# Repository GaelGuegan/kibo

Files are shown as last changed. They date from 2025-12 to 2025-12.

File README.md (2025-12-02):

# KIBO project

It consists of a panel of 5x5 addressable leds that could be configured through bluetooth.

It is powered by a 3.7V single cell lipo battery, that could be recharged through usb-c.

Leds are controlled by a single GPIO pin with signal passing through a 5V level shifter.

## Software

- Zephyr OS
- Android Studio

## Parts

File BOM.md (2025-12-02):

# BOM

* E73-2G4M08S1C: MCU Module with nRF52840
https://www.fr-ebyte.com/products/E73-2G4M08S1C

* WS2812B-2020: Leds x25
https://docs.nordicsemi.com/bundle/ncs-2.6.1/page/zephyr/samples/drivers/led_ws2812/README.html

* MT3608: Step Up Converter 3.3V -> 5V
https://www.olimex.com/Products/Breadboarding/BB-PWR-3608/resources/MT3608.pdf

* AP2112K-3.3: LDO regulator
https://www.diodes.com/assets/Datasheets/AP2112.pdf

* TP4057: Charger for battery
http://toppwr.com/uploadfile/file/20230304/640302a47b738.pdf

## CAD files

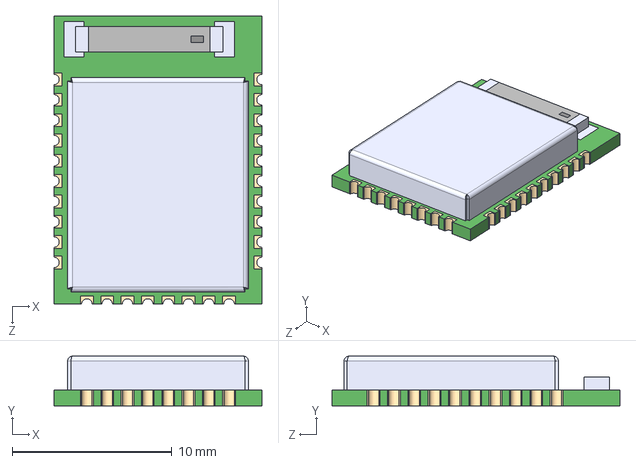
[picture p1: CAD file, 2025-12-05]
E73-2G4M08S1C/E73-2G4M08S1C.step
13.0 x 3.10 x 18.0 mm

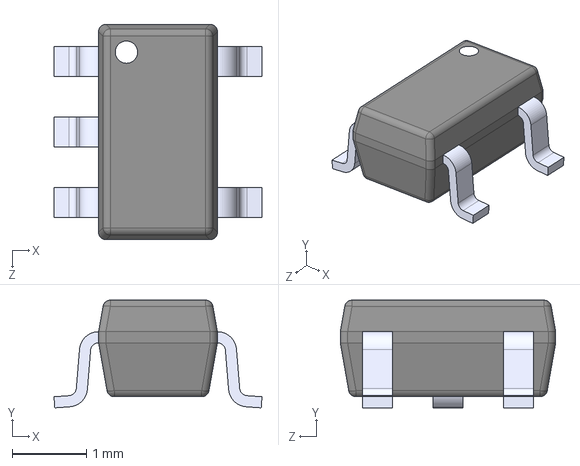
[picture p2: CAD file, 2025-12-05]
SN74AHCT1G125DBVT/SN74AHCT1G125DBVT.step
2.80 x 1.45 x 2.90 mm

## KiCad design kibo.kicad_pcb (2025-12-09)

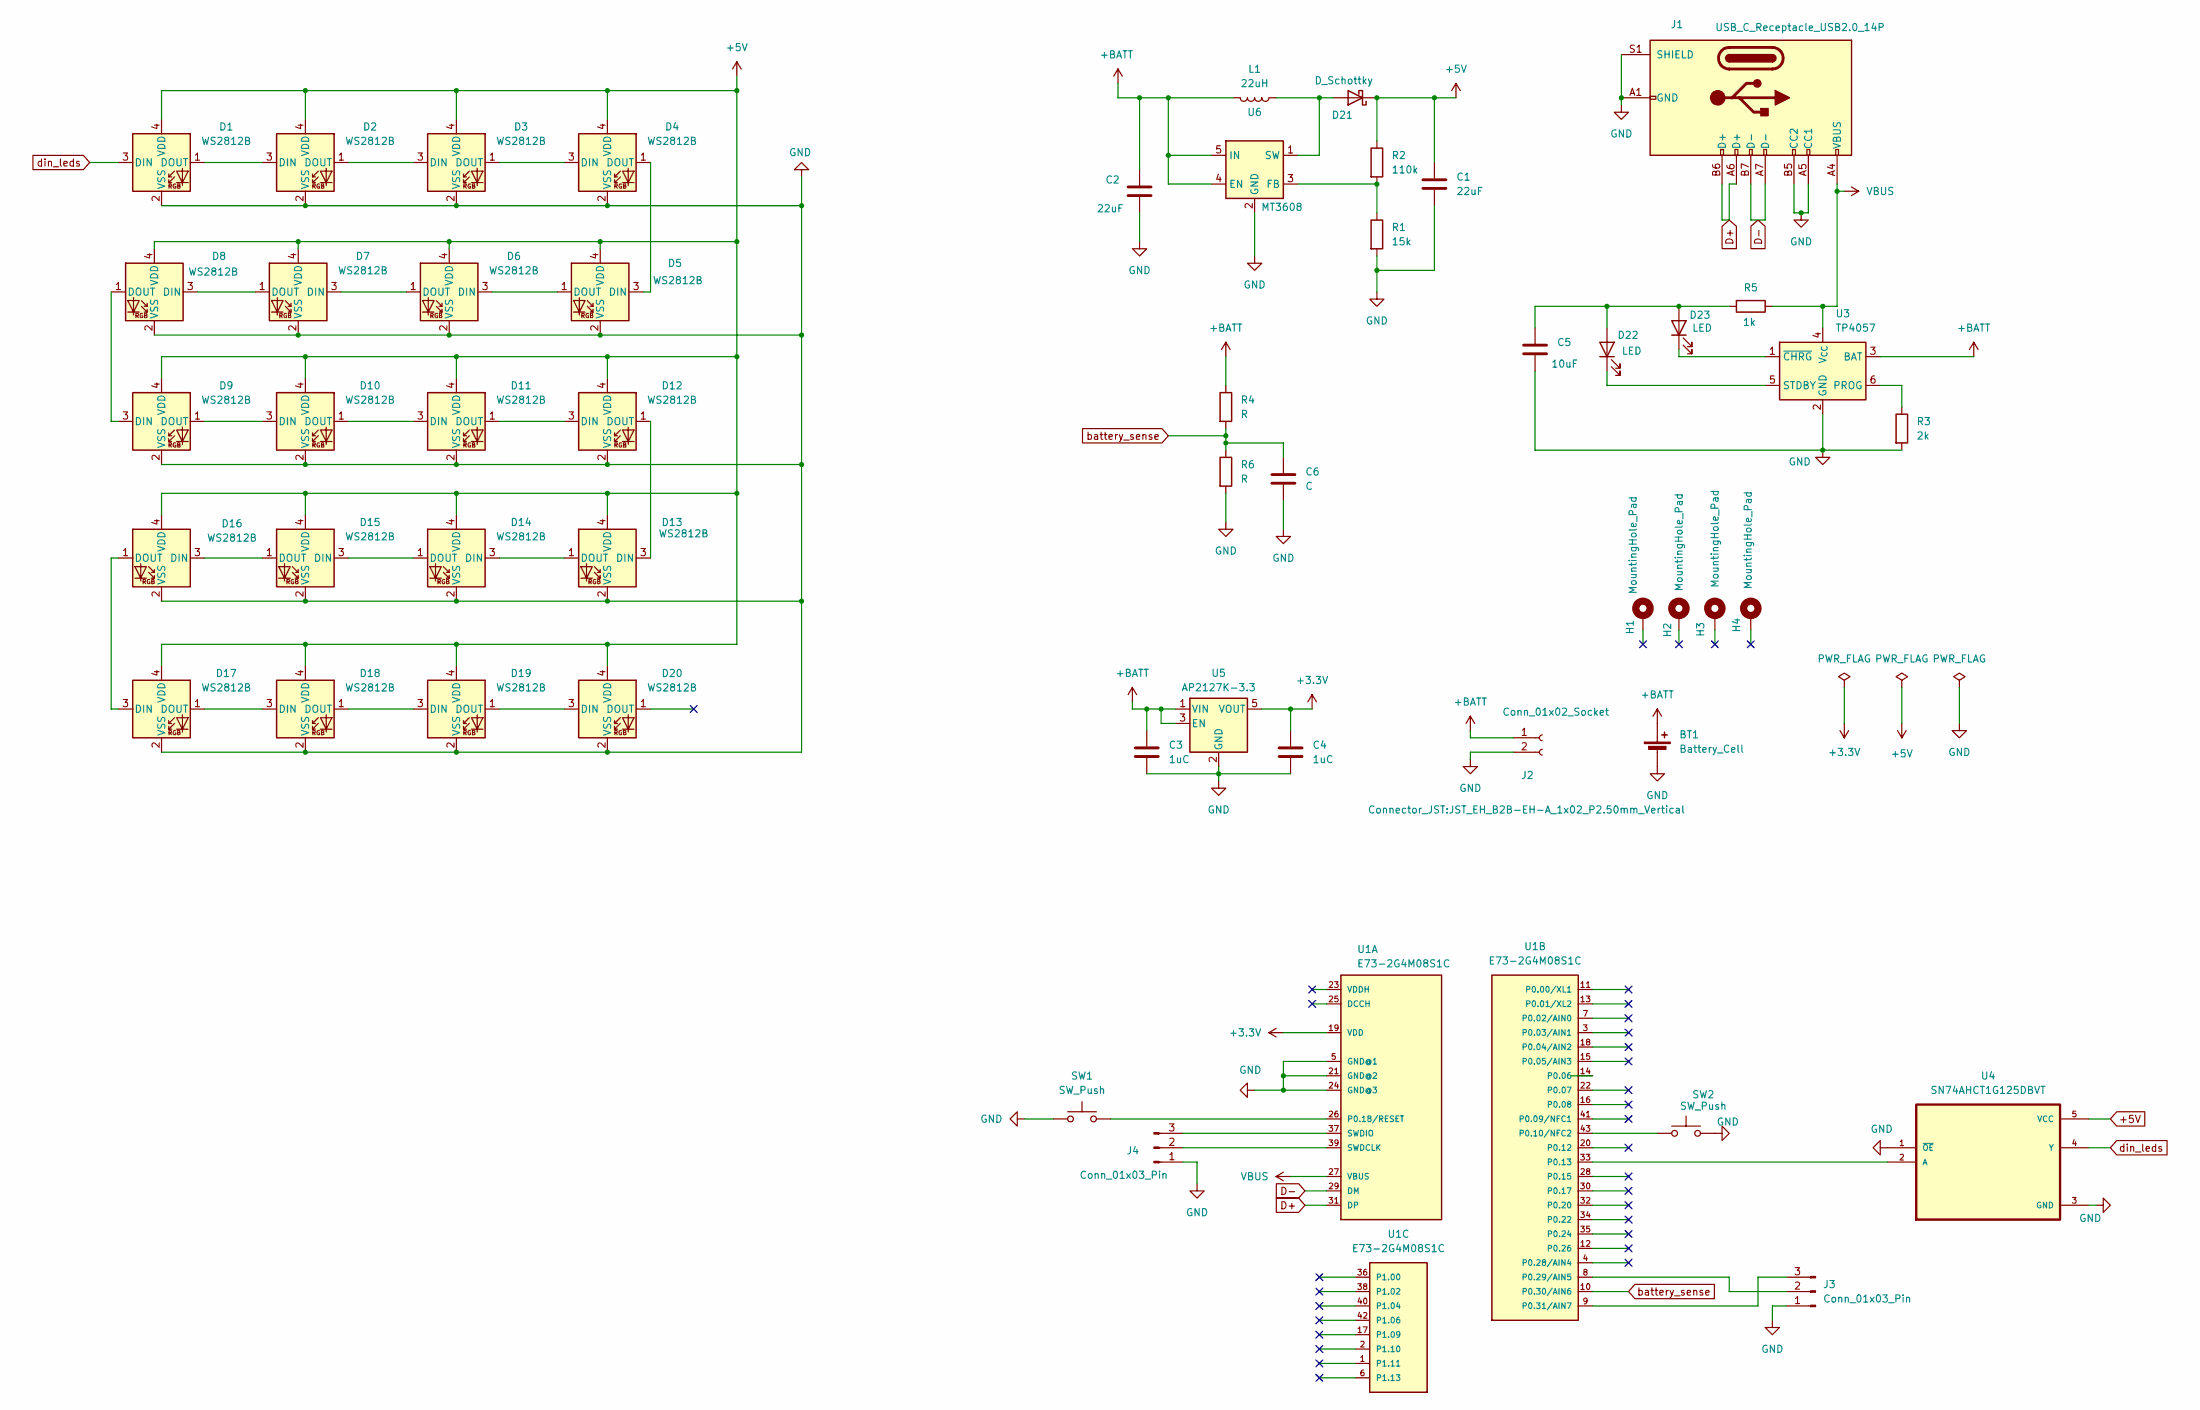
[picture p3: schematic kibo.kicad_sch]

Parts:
BT1: Battery_Cell
C1, C2: 22uF; C_0805_2012Metric
C3, C4: 1uC; C_0805_2012Metric
C5: 10uF; C_0805_2012Metric
C6: C; C_0805_2012Metric
D1, D2, D3, D4, D5, D6, D7, D8, D9, D10, D11, D12, D13, D14, D15, D16, D17, D18, D19, D20: WS2812B; LED_WS2812B-2020_PLCC4_2.0x2.0mm
D21: D_Schottky
D22, D23: LED
H1: MountingHole_Pad; MountingHole_2.5mm_Pad
H2, H3, H4: MountingHole_Pad; MountingHole_2.2mm_M2_Pad
J1: USB_C_Receptacle_USB2.0_14P; USB_C_Receptacle_Palconn_UTC16-G
J2: Conn_01x02_Socket; JST_EH_B2B-EH-A_1x02_P2.50mm_Vertical
J3, J4: Conn_01x03_Pin; PinHeader_1x03_P2.00mm_Vertical
L1: 22uH; L_0805_2012Metric
R1: 15k; R_0805_2012Metric
R2: 110k; R_0805_2012Metric
R3: 2k; R_0805_2012Metric
R4, R6: R; R_0805_2012Metric
R5: 1k; R_0805_2012Metric
SW1, SW2: SW_Push; SW_SPST_EVQP2_ShortPushTravel_H2.5mm
U1: E73-2G4M08S1C
U3: TP4057; TSOT-23-6
U4: SN74AHCT1G125DBVT; SOT95P280X145-5N
U5: AP2127K-3.3; SOT-23-5
U6: MT3608; SOT-23-6

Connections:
+3.3V: C4.1, U1.19 (VDD), U5.5 (VOUT)
+5V: C1.1, D1.4 (VDD), D2.4 (VDD), D3.4 (VDD), D4.4 (VDD), D5.4 (VDD), D6.4 (VDD), D7.4 (VDD), D8.4 (VDD), D9.4 (VDD), D10.4 (VDD), D11.4 (VDD), D12.4 (VDD), D13.4 (VDD), D14.4 (VDD), D15.4 (VDD), D16.4 (VDD), D17.4 (VDD), D18.4 (VDD), D19.4 (VDD), D20.4 (VDD), D21.1 (K), R2.1, U4.5 (VCC)
+BATT: BT1.1 (+), C2.1, C3.1, J2.1, L1.2, R4.1, U3.3 (BAT), U5.1 (VIN), U5.3 (EN), U6.4 (EN), U6.5 (IN)
D+: J1.A6 (D+), J1.B6 (D+), U1.31 (DP)
D-: J1.A7 (D-), J1.B7 (D-), U1.29 (DM)
GND: BT1.2 (-), C1.2, C2.2, C3.2, C4.2, C5.2, C6.2, D1.2 (VSS), D2.2 (VSS), D3.2 (VSS), D4.2 (VSS), D5.2 (VSS), D6.2 (VSS), D7.2 (VSS), D8.2 (VSS), D9.2 (VSS), D10.2 (VSS), D11.2 (VSS), D12.2 (VSS), D13.2 (VSS), D14.2 (VSS), D15.2 (VSS), D16.2 (VSS), D17.2 (VSS), D18.2 (VSS), D19.2 (VSS), D20.2 (VSS), J1.A1 (GND), J1.A5 (CC1), J1.A12 (GND), J1.B1 (GND), J1.B5 (CC2), J1.B12 (GND), J1.S1 (SHIELD), J2.2, J3.1, J4.1, R1.2, R3.2, R6.2, SW1.1, SW2.2, U1.5 (GND@1), U1.21 (GND@2), U1.24 (GND@3), U3.2 (GND), U4.1 (~OE), U4.3 (GND), U5.2 (GND), U6.2 (GND)
unnamed: D1.1 (DOUT), D2.3 (DIN)
unnamed: D2.1 (DOUT), D3.3 (DIN)
unnamed: D3.1 (DOUT), D4.3 (DIN)
unnamed: D4.1 (DOUT), D5.3 (DIN)
unnamed: D5.1 (DOUT), D6.3 (DIN)
unnamed: D6.1 (DOUT), D7.3 (DIN)
unnamed: D7.1 (DOUT), D8.3 (DIN)
unnamed: D8.1 (DOUT), D9.3 (DIN)
unnamed: D9.1 (DOUT), D10.3 (DIN)
unnamed: D10.1 (DOUT), D11.3 (DIN)
unnamed: D11.1 (DOUT), D12.3 (DIN)
unnamed: D12.1 (DOUT), D13.3 (DIN)
unnamed: D13.1 (DOUT), D14.3 (DIN)
unnamed: D14.1 (DOUT), D15.3 (DIN)
unnamed: D15.1 (DOUT), D16.3 (DIN)
unnamed: D16.1 (DOUT), D17.3 (DIN)
unnamed: D17.1 (DOUT), D18.3 (DIN)
unnamed: D18.1 (DOUT), D19.3 (DIN)
unnamed: D19.1 (DOUT), D20.3 (DIN)
unnamed: D21.2 (A), L1.1, U6.1 (SW)
unnamed: C5.1, D22.2 (A), D23.2 (A), R5.2
unnamed: D22.1 (K), U3.5 (STDBY)
unnamed: D23.1 (K), U3.1 (~CHRG)
unnamed: J3.2, U1.8 (P0.29/AIN5)
unnamed: J3.3, U1.9 (P0.31/AIN7)
unnamed: J4.2, U1.39 (SWDCLK)
unnamed: J4.3, U1.37 (SWDIO)
unnamed: SW1.2, U1.26 (P0.18/RESET)
unnamed: SW2.1, U1.43 (P0.10/NFC2)
unnamed: U1.33 (P0.13), U4.2 (A)
unnamed: R3.1, U3.6 (PROG)
unnamed: R1.1, R2.2, U6.3 (FB)
VBUS: J1.A4 (VBUS), J1.A9 (VBUS), J1.B4 (VBUS), J1.B9 (VBUS), R5.1, U1.27 (VBUS), U3.4 (V_{CC})
battery_sense: C6.1, R4.2, R6.1, U1.10 (P0.30/AIN6)
din_leds: D1.3 (DIN), U4.4 (Y)

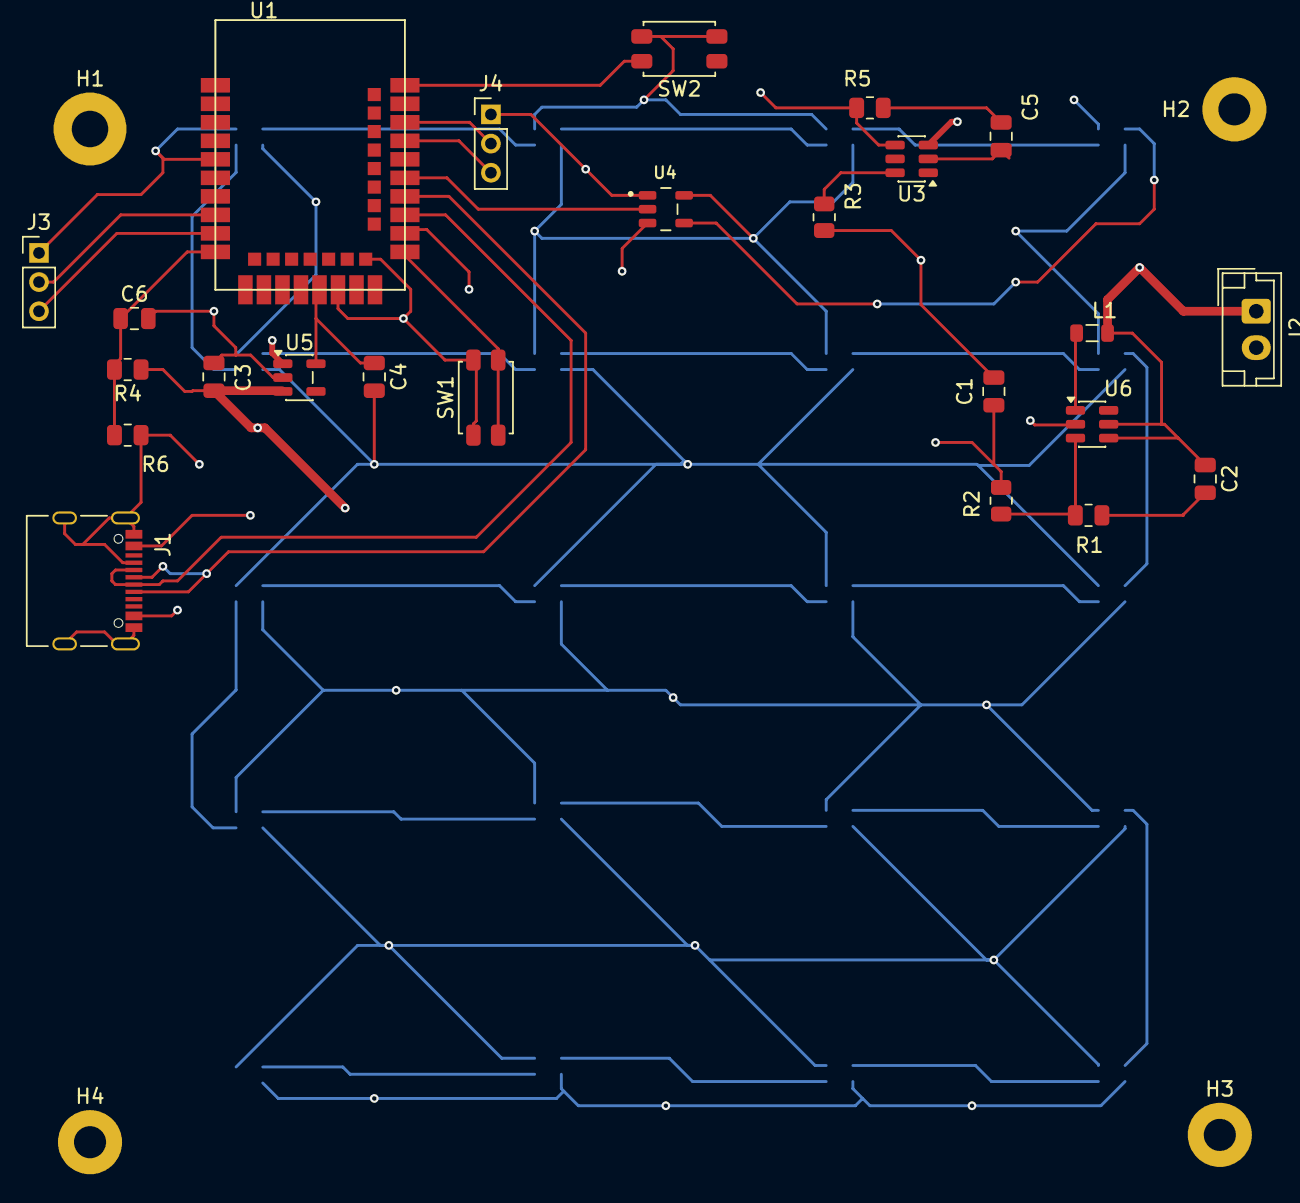
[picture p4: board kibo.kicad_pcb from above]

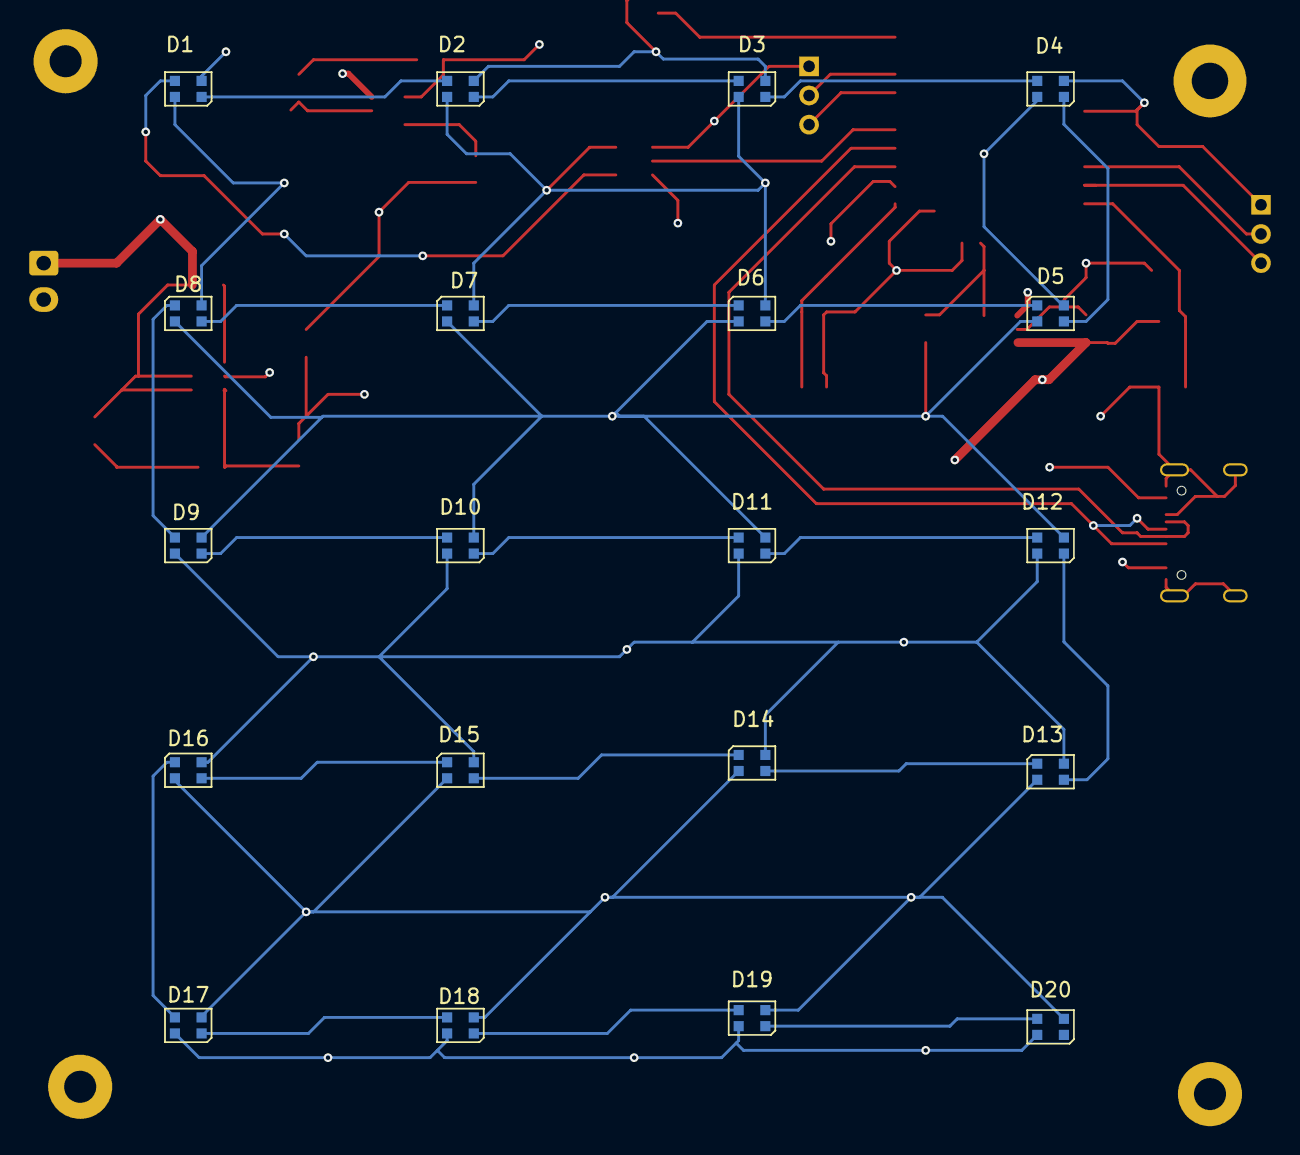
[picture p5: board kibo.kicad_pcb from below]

Board: 4 copper layers, 48 parts (20 on the bottom side), 39 nets.

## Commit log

2025-10-22 Update schematics
    [kibo.kicad_sch]
2025-12-02 Remove datasheet and add BOM
2025-12-05 fisrt version minimal
    [E73-2G4M08S1C.step, SN74AHCT1G125DBVT.step, kibo.kicad_pcb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]
2025-12-09 update schematic
    [kibo.kicad_pcb, kibo.kicad_sch]
